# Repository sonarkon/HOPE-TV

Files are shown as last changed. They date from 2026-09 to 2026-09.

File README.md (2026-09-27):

# HopeTV

A tiny WiFi-connected "TV" built from a Wemos D1 mini (ESP8266) and a 1.44"
128x128 SPI TFT display (ST7735). Shows a color test pattern, classic
black/white TV static, a bouncing-ball animation, a playlist of looping
Motion-JPEG clips and still images, or a dedicated photo slideshow — all
remote-controllable over OSC (or a Serial console, for testing without an
OSC sender).

## Hardware

- Wemos D1 mini (ESP8266 / ESP-12)
- 1.44" SPI TFT, 128x128, ST7735 driver (commonly sold as "1.44 TFT LCD
  Display Module ST7735 128x128")
- USB power (5V) or a regulated 3.0–3.6V source wired directly to the 3V3 pin

## Pinout

One firmware, two supported wiring layouts — which one is active is chosen
at runtime via the `pinout` key in `config.txt` (`v2` or `prototyp`, see
below), no code changes needed. `v2` is the current/default board with a
re-laid-out, shorter-wire layout; `prototyp` is the original wiring.

| Display pin | `v2` (default) | `prototyp` (original) | Note |
|---|---|---|---|
| VCC | 3V3 | 3V3 | |
| GND | GND | GND | |
| CS | D4 (GPIO2) | D2 (GPIO4) | deliberately never D8 (boot issues) |
| RESET | D3 (GPIO0) | D4 (GPIO2) | |
| A0 / DC | D2 (GPIO4) | D3 (GPIO0) | |
| SDA / MOSI | D7 (GPIO13) | D7 (GPIO13) | Hardware SPI MOSI, fixed on the ESP8266 |
| SCK | D5 (GPIO14) | D5 (GPIO14) | Hardware SPI SCK, fixed on the ESP8266 |
| LED / Backlight | D1 (GPIO5) | D1 (GPIO5) | PWM-controlled, see Brightness/Power note below |

D0 and D8 are deliberately avoided in both layouts: they have special
boot-strapping functions and can easily cause boot loops or a dead display.

### Brightness/Power

The backlight LED is wired to **D1 (GPIO5)**, not straight to 3V3, so
`/hopetv/brightness` and `/hopetv/power` can dim/switch it via PWM. Per the
module's datasheet, the LED pin is a 3.3V logic control input ("high level
lighting"), not a raw LED — driving it directly from a GPIO without a
transistor is fine.

## Setup

1. **Board package**: add `http://arduino.esp8266.com/stable/package_esp8266com_index.json`
   under Additional Board Manager URLs, then install the ESP8266 package and
   select board **"LOLIN(WEMOS) D1 R2 & mini"**.
2. **Flash size**: Tools → Flash Size → a scheme with at least ~2MB of
   filesystem space (e.g. "4MB (FS:3MB OTA:~512KB)").
3. **Libraries** (via Library Manager):
   - `Adafruit GFX Library`
   - `Adafruit ST7735 and ST7789 Library` (a version with `enableDisplay()`)
   - `OSC` (by CNMAT / Adrian Freed)
   - `JPEGDEC` (by bitbank2)
4. **WiFi/OSC config**: copy `hopetv/data/config.example.txt` to
   `hopetv/data/config.txt` and fill in your own `ssid`/`password` (and
   `pinout`, if you're on the `prototyp` wiring). `config.txt` is gitignored
   on purpose — never commit your real WiFi credentials.
5. **Upload the data folder** with a LittleFS uploader (IDE 2.x: the
   [arduino-littlefs-upload](https://github.com/earlephilhower/arduino-littlefs-upload)
   plugin, run via the command palette — "Upload LittleFS to Pico/ESP8266/ESP32";
   IDE 1.8.x: the "ESP8266 LittleFS Data Upload" menu item). This uploads
   `config.txt`, the clip files, and `slideshow/`.
6. **Flash the sketch** normally.

If `config.txt` is missing, the sketch falls back to the placeholder
defaults hardcoded in the `.ino` file (`YOUR_WIFI_SSID` / `YOUR_WIFI_PASSWORD`),
which will simply fail to connect — always use a real `config.txt` for
actual WiFi use.

WiFi connects in the background: `WiFi.begin()` fires immediately at boot
(non-blocking), while the boot screen draws the clip list etc.; by the time
it actually waits for a result, part or all of the connect time has usually
already passed. Listing found clip names on the boot screen is capped at a
total of 5 seconds regardless of how many there are (a fixed 1s/clip
delay doesn't scale once you have a dozen+ clips).

## Clip playback (Motion-JPEG / stills)

Drop any number of 128x128 clip files into `data/` and upload them with the
filesystem tool — they're auto-detected at boot (sorted alphabetically,
addressable by index 0, 1, 2, ... — see the Serial `clips` command), and
each plays with the decoder matching its extension:

| Extension | Decoder | Notes |
|---|---|---|
| `.mjpg` | custom Motion-JPEG player (see below), via `JPEGDEC` | the only animated clip format |
| `.jpg` / `.jpeg` | `JPEGDEC`, decoded once | a lone still image, just held on screen |

**No animated-GIF support** — it was dropped deliberately. `AnimatedGIF`'s
own global decode-state object alone used ~24KB; combined with `JPEGDEC`
(added for stills/slideshow, ~18KB heap-allocated) that left almost no RAM
headroom on the ESP8266's small 80KB region for global/static variables
(90% used, no room for anything else). Dropping `AnimatedGIF` and
re-encoding old `.gif` clips as `.mjpg` instead brought that down to 60% —
and the two example clips got *smaller* in the process (see below). Old
`.gif` files can be converted the same way as any other source video (just
point ffmpeg at the `.gif` as input instead of a video file).

By default the device boots straight into clip mode and loops `clip2.mjpg`
if present, otherwise the first file found; no cycling through the other
modes unless you turn that on explicitly (`/hopetv/auto 1`) — and no
auto-advancing through the whole clip playlist either, `/hopetv/clip
<index>` (or the Serial `clip` command) just jumps to and loops/holds one
specific clip.

**`.mjpg` is not a standard container** — it's a tiny custom format made for
this project (see `tools/frame_mjpeg.py`): repeated `[4-byte little-endian
frame length][that many JPEG bytes]`, nothing else. That makes on-device
frame reading trivial (a length-prefixed read, no marker-scanning), at the
cost of not being playable by anything other than this firmware.

**Creating a new `.mjpg` clip**, roughly (adjust the crop values to your
source video/GIF — check for letterboxing/aspect ratio first):

```bash
ffmpeg -i input.mov -vf "crop=<w>:<h>:<x>:<y>,scale=128:128:flags=lanczos,fps=12" \
  -c:v mjpeg -huffman default -pix_fmt yuvj420p -q:v 10 -an -f mjpeg raw.mjpeg
python3 tools/frame_mjpeg.py raw.mjpeg clipN.mjpg
```

**`-huffman default -pix_fmt yuvj420p` are required, not optional.** FFmpeg's
mjpeg encoder defaults to per-frame-optimized ("optimal") Huffman tables and
a non-canonical chroma subsampling layout; both are valid JPEG but JPEGDEC
(the decoder this firmware uses) fails to decode the vast majority of frames
encoded that way — the exact symptom is clips/stills that look glitchy
(color noise, torn/shifted rows, wrong colors) on the device, verified by
running every frame of an affected clip through JPEGDEC's own reference
decoder offline. `-huffman default` forces the standard JPEG Huffman tables
and `-pix_fmt yuvj420p` forces canonical 4:2:0 subsampling — together these
reliably produce frames JPEGDEC decodes correctly.

Keep clips short (a few seconds) — file size scales with length; `q:v 10`
at 12fps runs well under 100KB for a several-second clip. LittleFS space is
limited to a few MB total.

## Slideshow

A separate, dedicated mode for cycling through photos, independent of the
clip playlist above: drop `.jpg`/`.jpeg` stills into `data/slideshow/` and
upload them — `/hopetv/slideshow 1` (or Serial `slideshow 1`) switches to
it, each image is shown before auto-advancing to the next, looping forever.
`/hopetv/slideshow 0` returns to clip mode. Default is 4 seconds/image,
adjustable with `/hopetv/slideshow/speed <seconds>` (or Serial `slidespeed
<seconds>`), e.g. `slidespeed 2.5`.

Optionally, each transition can fade to black, swap the image, then fade
back in via backlight PWM dimming, same mechanism as `/hopetv/brightness`.
Off by default; enable/adjust it with `/hopetv/slideshow/fade <ms>` (or
Serial `slidefade <ms>`), where `<ms>` is the total fade duration (0 turns
it off again), e.g. `slidefade 1000` for a 1-second fade. This isn't a true
pixel crossfade between the two images (that would need two full 128x128
framebuffers in RAM at once, ~64KB, more than reliably fits alongside WiFi +
JPEGDEC), but reads as a clean fade transition in practice.

```bash
ffmpeg -i input.jpg -vf "crop=min(iw\,ih):min(iw\,ih):(iw-min(iw\,ih))/2:(ih-min(iw\,ih))/2,\
scale=128:128:flags=lanczos" -huffman default -pix_fmt yuvj420p -update 1 -q:v 5 output.jpg
```

Same `-huffman default -pix_fmt yuvj420p` requirement as clips above (see
note there) — without it, stills decode just as unreliably as clips do.

## OSC commands (default port 9000)

| Address | Type | Meaning |
|---|---|---|
| `/hopetv/mode` | int (0-3) | 0=test pattern, 1=noise, 2=animation, 3=clip; disables auto-cycling |
| `/hopetv/auto` | int (0/1) | auto mode-cycling off/on |
| `/hopetv/debug` | int (0-2) | 0=off, 1=info screen (IP/port/clip+slide count/last command), 2=file list of found clips (paginated every 2s if needed) |
| `/hopetv/power` | int (0/1) | display off/on |
| `/hopetv/brightness` | float (0.0-1.0) | backlight brightness |
| `/hopetv/fps` | float (1-60) | frame rate for noise/animation (MJPEG clips run at their own native pace) |
| `/hopetv/bw` | int (0/1) | black & white filter, applied to test pattern, animation, and all clip/slideshow playback |
| `/hopetv/clip` | int (index) | select a clip by index (0-based, alphabetical — see Serial `clips`), switches to clip mode |
| `/hopetv/clip/id` | int (number) | select a clip by its filename number prefix (e.g. `3` → `03_mond_1.jpg`), independent of list position; Serial `clipid 3` |
| `/hopetv/slideshow` | int (0/1) | slideshow mode off/on (see Slideshow section above) |
| `/hopetv/slideshow/speed` | float (seconds) | seconds per slideshow image (default 4) |
| `/hopetv/slideshow/fade` | int (ms) | total fade transition duration; 0 = off (default) |

The address must match exactly (lowercase, one leading slash, no spaces) or
the message is received but ignored. Every received OSC message is echoed
over Serial (`OSC empfangen: <address> <value>`) followed by whether it
matched a known command — and in debug mode 1, the on-screen "Letzter OSC:"
line shows `[OK]` or `[?]` right next to the last command, so a typo in the
sender is easy to spot without a Serial Monitor open.

## Testing without an OSC sender

The exact same set of commands also works by typing into the Serial Monitor
(115200 baud, line ending set to "Newline") — just drop the `/hopetv/`
prefix: `mode 3`, `brightness 0.5`, `clip 1`, `slideshow 1`, `slidespeed
2.5`, `slidefade 1000`, `clips` (lists found clips + slide count), `help`
(full command list).

## Repo layout

```
hopetv/             the sketch: hopetv.ino, data/ (clips, slideshow/, config),
                     videoclips/ (raw source clips/photos, gitignored),
                     3d print/ (enclosure STL files)
tools/               frame_mjpeg.py - converts a raw ffmpeg MJPEG stream into
                     the custom length-prefixed .mjpg format this firmware reads
```

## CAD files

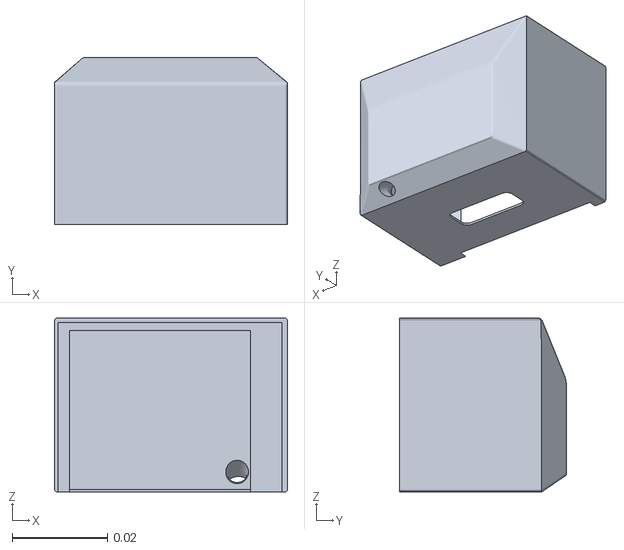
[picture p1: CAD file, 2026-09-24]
hopetv/3d print/back_3.stl
0.049 x 0.0351 x 0.0366

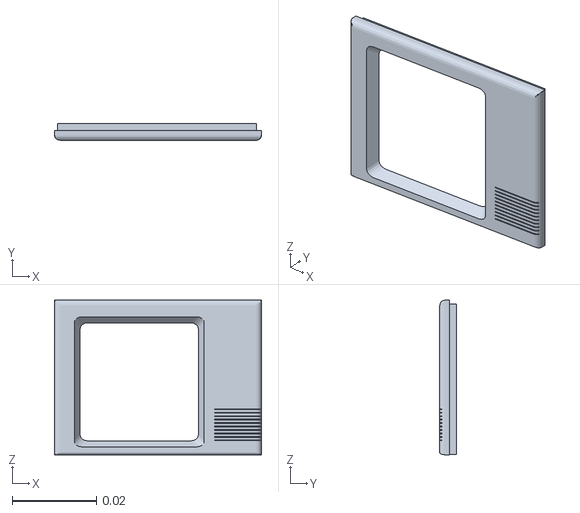
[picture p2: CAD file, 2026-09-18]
hopetv/3d print/front_3.stl
0.0491 x 0.00393 x 0.0367

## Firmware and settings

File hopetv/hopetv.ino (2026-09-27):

// D1 mini (ESP8266/ESP-12) + 1.44" SPI TFT 128x128 (ST7735, "v1.1" China clone module)
//
// Wiring (Hardware SPI):
//   LED/Backlight -> D1 (GPIO5) - PWM-controlled, see Brightness/Power note below
//   SCK           -> D5 (GPIO14)
//   SDA/MOSI      -> D7 (GPIO13)
//   A0/DC         -> D3 (GPIO0)
//   RESET         -> D4 (GPIO2)
//   CS            -> D2 (GPIO4)
//   VCC           -> 3V3
//   GND           -> GND
//
// Brightness/Power:
//   The backlight LED is wired to D1 (GPIO5), not straight to 3V3, so
//   /hopetv/brightness and /hopetv/power can dim/switch it via PWM. Per the
//   manufacturer datasheet, the LED pin is a logic control input (3.3V TTL,
//   "high level lighting"), not a raw LED pin - driving it directly from a
//   GPIO without a transistor is fine.
//
// Libraries (install via the Library Manager):
//   "Adafruit GFX Library"
//   "Adafruit ST7735 and ST7789 Library" (version with enableDisplay()!)
//   "OSC" (by CNMAT / Adrian Freed)
//   "JPEGDEC" (by bitbank2)
// LittleFS, ESP8266WiFi, WiFiUdp are part of the ESP8266 board package.
//
// Clip files: drop any number of .mjpg / .jpg(.jpeg) files (128x128) into
// the /data folder and upload them with the "ESP8266 LittleFS Data Upload"
// plugin - they are auto-detected at boot (sorted alphabetically,
// addressable via index 0,1,2,..., see the serial command "clips"), and each
// plays with the decoder matching its extension: .mjpg via a small custom
// Motion-JPEG player (see below), a lone .jpg/.jpeg is treated as a still
// image and just held on screen. (No animated-GIF support: it was dropped
// deliberately - the AnimatedGIF library's own global decode-state object
// alone used ~24KB, which combined with JPEGDEC left no RAM headroom on the
// ESP8266's small 80KB region for global/static variables. Re-encode old
// .gif clips to .mjpg with tools/frame_mjpeg.py instead - typically smaller
// files too.) Default behavior: the device boots straight into clip mode
// and loops clip2.mjpg if present, otherwise the first file found (no
// auto-cycling through all modes).
//
// .mjpg format: NOT a standard container - a simple custom format made for
// this project (see ../tools/frame_mjpeg.py in the repo root): repeated
// [4-byte little-endian frame length][one JFIF/JPEG frame's bytes], nothing
// else. Makes on-device frame reading trivial (no marker-scanning needed).
// To make one: encode a short 128x128 clip as concatenated JPEG frames with
// ffmpeg, e.g.
//   ffmpeg -i input.mov -vf fps=12 -c:v mjpeg -q:v 10 -an -f mjpeg raw.mjpeg
// then run `python3 tools/frame_mjpeg.py raw.mjpeg output.mjpg`.
//
// Slideshow: separate, dedicated mode - put .jpg/.jpeg stills into
// /data/slideshow/ and upload them; they auto-advance every N seconds
// (default 4, see /hopetv/slideshow/speed), looping forever, independent
// of the main clip playlist above.
//
// Optional: /data/config.txt for SSID/password/OSC port without reflashing.
//
// OSC commands (port from config.txt / default 9000):
//   /hopetv/mode           int   0=Test pattern 1=Noise 2=Animation 3=Clip
//   /hopetv/auto           int   0/1  auto mode-cycling off/on
//   /hopetv/debug          int   0=off 1=info (IP/port/clip+slide count/last command)
//                                 2=file list (found clips, paginated every 2s)
//   /hopetv/power          int   0/1  display off/on
//   /hopetv/brightness     float 0.0-1.0  backlight brightness (see note above)
//   /hopetv/fps            float 1-60  frame rate for noise/animation
//   /hopetv/bw             int   0/1  black & white filter off/on
//   /hopetv/clip           int   index  select a clip by index (0-based, alphabetically
//                                 sorted, see serial "clips"), switches to clip mode
//   /hopetv/clip/id        int   number  select a clip by its filename number prefix
//                                 (e.g. 3 -> "03_mond_1.jpg"), independent of list position (id, not index)
//   /hopetv/slideshow      int   0/1  slideshow mode off/on (see above)
//   /hopetv/slideshow/speed float seconds per slideshow image (default 4)
//   /hopetv/slideshow/fade int   ms   total fade transition duration; 0 = off (default)
//
// The same commands also work via the Serial Monitor (115200 baud, line
// ending "Newline"), no OSC sender needed for testing: e.g. "mode 3",
// "brightness 0.5", "clip 1", "slidespeed 2.5", "slidefade 1000".
// "help" shows the full list.
// IMPORTANT: serial commands need NO "/hopetv/" prefix (just "mode 3"), but
// real OSC messages DO (full "/hopetv/mode 3", exact, lowercase, one leading
// slash) - otherwise the message is received/displayed but no action is
// executed. In debug mode 1, "Last OSC:" shows [OK] (address recognized) or
// [?] (no matching address) right after the last command.

#include <Adafruit_GFX.h>
#include <Adafruit_ST7735.h>
#include <SPI.h>
#include <ESP8266WiFi.h>
#include <WiFiUdp.h>
#include <LittleFS.h>
#include <OSCMessage.h>
#include <JPEGDEC.h>

Adafruit_ST7735 *tft;
int8_t pinCS, pinDC, pinRST, pinBacklight;

struct Config {
  String ssid = "YOUR_WIFI_SSID";
  String password = "YOUR_WIFI_PASSWORD";
  uint16_t oscPort = 9000;
  String pinout = "v2"; // "v2" (default, new board) or "prototyp" (old pinout)
} config;

// Pinout "prototyp": CS=D2 DC=D3 RST=D4 LED=D1 (hardware SPI SCK=D5/MOSI=D7 always fixed)
// Pinout "v2":       CS=D4 DC=D2 RST=D3 LED=D1
void waehlePinout() {
  if (config.pinout == "prototyp") {
    pinCS = D2;
    pinDC = D3;
    pinRST = D4;
    pinBacklight = D1;
  } else {
    pinCS = D4;
    pinDC = D2;
    pinRST = D3;
    pinBacklight = D1;
  }
  Serial.print("Pinout: ");
  Serial.println(config.pinout);
}

WiFiUDP udp;

// Allocated on the heap in setup(), not a global object: JPEGDEC's internal
// decode buffers/Huffman tables are ~18KB, which alone would overflow the
// ESP8266's small (80KB) fixed region for global/static variables.
JPEGDEC *jpeg;

enum ClipTyp { CLIP_MJPG, CLIP_STILL };

#define MAX_CLIPS 48
String clipListe[MAX_CLIPS];
ClipTyp clipTypListe[MAX_CLIPS];
int anzahlClips = 0;
String aktuellerClipPfad = "/01_clip2.mjpg"; // may be overridden by sucheClips()/waehleStandardClip()
ClipTyp aktuellerClipTyp = CLIP_MJPG;

// Motion-JPEG playback (custom .mjpg container, see header comment above)
File mjpgFile;
bool mjpgOffen = false;
uint8_t mjpgFrameBuf[8192]; // generous headroom over the ~3.3KB max frame seen so far
const unsigned long MJPG_FRAME_MS = 83; // ~12 fps, matches how clips are encoded

// Slideshow: separate file list + own mode, independent of the clip playlist
#define MAX_SLIDES 32
String slideListe[MAX_SLIDES];
int anzahlSlides = 0;
int slideIndex = 0;
unsigned long slideStart = 0;
unsigned long slideDauerMs = 4000; // per image, adjustable via /hopetv/slideshow/speed
unsigned long slideFadeMs = 0; // total fade transition duration; 0 = off (default), see /hopetv/slideshow/fade

// Mode name kept as "GIFMODUS" for historical reasons (this used to be
// GIF-only) - it's now the general clip-playlist mode (MJPEG + stills).
enum Mode { TESTBILD, RAUSCHEN, ANIMATION, GIFMODUS, SLIDESHOW, DEBUG };
Mode mode = GIFMODUS; // default: loop the default clip directly, no auto-cycling
bool autoCycle = false;
bool powerOn = true;
bool bwFilter = false;
float brightness = 1.0f;
unsigned long modeStart = 0;
const unsigned long MODE_DAUER = 6000; // ms per mode

unsigned long frameIntervalMs = 33; // ~30 fps initial default
unsigned long lastFrame = 0;
unsigned long lastDebugDraw = 0;
int debugModus = 0; // 0=off, 1=info, 2=file list
Mode modusVorDebug = GIFMODUS; // saved on entering debug mode, restored on exit
bool autoCycleVorDebug = false;
int filelistSeite = 0;
int filelistSeitenAnzahl = 1;
const int FILELIST_ZEILEN_PRO_SEITE = 8;
int letzteHelligkeitProzent = -1;
int letzteFps = -1;
String letzterAngezeigterOsc = "";
String letzterOscBefehl = "-";

bool bootSplashActive = true;
unsigned long bootSplashStart = 0;
const unsigned long BOOT_SPLASH_DAUER = 3000; // IP/status display time after WiFi result, before clip playback starts
unsigned long wlanStartZeit = 0; // set by starteWLAN(), used to cap the total connect wait

// State for the ball animation
float ballX = 64, ballY = 64;
float ballVX = 2.3, ballVY = 1.7;
const int ballR = 6;

void setup() {
  Serial.begin(115200);

  ladeConfig(); // mounts LittleFS, reads SSID/password/port/pinout
  waehlePinout();
  sucheClips();
  sucheSlideshow();
  waehleStandardClip();

  tft = new Adafruit_ST7735(pinCS, pinDC, pinRST);
  tft->initR(INITR_144GREENTAB); // correct for 1.44" 128x128 v1.1
  tft->setRotation(1); // +90 degrees (was -90, rotated another 180)
  tft->fillScreen(ST77XX_BLACK);

  pinMode(pinBacklight, OUTPUT);
  analogWriteRange(1023);
  setzeHelligkeit(brightness);

  jpeg = new JPEGDEC();

  Serial.println("Standard-Clip: " + aktuellerClipPfad + " (Typ: " + String(aktuellerClipTyp == CLIP_MJPG ? "MJPG" : "STILL") + ")");

  // Fire off the WiFi connection now (non-blocking) so it happens in the
  // background while the boot sequence below draws the clip list etc. -
  // by the time we get to actually waiting for it, some/all of the connect
  // time has likely already elapsed.
  starteWLAN();

  bootSplashActive = true;
  bootSplashStart = millis();
  zeichneBootSequenz();
}

void loop() {
  pruefeOSC();
  pruefeSerialBefehle();

  if (bootSplashActive) {
    if (millis() - bootSplashStart > BOOT_SPLASH_DAUER) {
      bootSplashActive = false;
      tft->fillScreen(ST77XX_BLACK);
      if (mode == TESTBILD) zeichneTestbild();
      modeStart = millis();
    }
    return;
  }

  if (!powerOn) return;

  if (mode == SLIDESHOW) {
    if (millis() - slideStart > slideDauerMs) {
      zeigeSlide(slideIndex + 1);
    }
    return;
  }

  if (mode == DEBUG) {
    if (debugModus == 2) {
      // only redraw at all when there are multiple pages (to page through) -
      // if everything fits on one page it was already drawn on entry
      if (filelistSeitenAnzahl > 1 && millis() - lastDebugDraw > 2000) {
        zeichneDateiliste();
        lastDebugDraw = millis();
      }
    } else if (millis() - lastDebugDraw > 1000) {
      zeichneDebugDynamisch();
      lastDebugDraw = millis();
    }
    return;
  }

  if (autoCycle && millis() - modeStart > MODE_DAUER) {
    modeStart = millis();
    if (mode == GIFMODUS) beendeMjpeg();
    mode = (Mode)((mode + 1) % 4); // cycles TESTBILD/RAUSCHEN/ANIMATION/GIFMODUS
    tft->fillScreen(ST77XX_BLACK);
    if (mode == TESTBILD) zeichneTestbild();
    else if (mode == GIFMODUS && aktuellerClipTyp == CLIP_STILL) zeigeStandbild(aktuellerClipPfad);
  }

  if (mode == GIFMODUS) {
    if (aktuellerClipTyp == CLIP_MJPG) {
      if (millis() - lastFrame >= MJPG_FRAME_MS) {
        lastFrame = millis();
        spieleMjpegFrame();
      }
    }
    // CLIP_STILL: nothing to do each frame, already drawn once on selection
  } else if (millis() - lastFrame >= frameIntervalMs) {
    lastFrame = millis();
    switch (mode) {
      case TESTBILD:
        // already drawn, nothing to do
        break;
      case RAUSCHEN:
        zeichneRauschen();
        break;
      case ANIMATION:
        animiereBall();
        break;
      default:
        break;
    }
  }
}

void ladeConfig() {
  if (!LittleFS.begin()) {
    Serial.println("LittleFS-Mount fehlgeschlagen, nutze Standardwerte");
    return;
  }
  if (!LittleFS.exists("/config.txt")) {
    Serial.println("Keine config.txt gefunden, nutze Standardwerte");
    return;
  }
  File f = LittleFS.open("/config.txt", "r");
  while (f.available()) {
    String line = f.readStringUntil('\n');
    line.trim();
    if (line.length() == 0 || line.startsWith("#")) continue;
    int eq = line.indexOf('=');
    if (eq < 0) continue;
    String key = line.substring(0, eq);
    String val = line.substring(eq + 1);
    key.trim();
    val.trim();
    if (key == "ssid") config.ssid = val;
    else if (key == "password") config.password = val;
    else if (key == "oscport") config.oscPort = (uint16_t)val.toInt();
    else if (key == "pinout") config.pinout = val;
  }
  f.close();
  Serial.println("config.txt geladen");
}

// Recognizes .mjpg (custom container, see header) and .jpg/.jpeg (single
// still image) - anything else in the root folder is ignored, so e.g.
// config.txt or the slideshow/ subfolder are naturally skipped.
void sucheClips() {
  anzahlClips = 0;
  Dir dir = LittleFS.openDir("/");
  while (dir.next() && anzahlClips < MAX_CLIPS) {
    String name = dir.fileName();
    String nameLower = name;
    nameLower.toLowerCase();
    ClipTyp typ;
    if (nameLower.endsWith(".mjpg")) typ = CLIP_MJPG;
    else if (nameLower.endsWith(".jpg") || nameLower.endsWith(".jpeg")) typ = CLIP_STILL;
    else continue;
    if (!name.startsWith("/")) name = "/" + name;
    clipListe[anzahlClips] = name;
    clipTypListe[anzahlClips] = typ;
    anzahlClips++;
  }
  // simple sort (alphabetical, both arrays in lockstep), lists are small
  for (int i = 0; i < anzahlClips - 1; i++) {
    for (int j = 0; j < anzahlClips - 1 - i; j++) {
      if (clipListe[j] > clipListe[j + 1]) {
        String tauschName = clipListe[j];
        clipListe[j] = clipListe[j + 1];
        clipListe[j + 1] = tauschName;
        ClipTyp tauschTyp = clipTypListe[j];
        clipTypListe[j] = clipTypListe[j + 1];
        clipTypListe[j + 1] = tauschTyp;
      }
    }
  }
  filelistSeitenAnzahl = max(1, (anzahlClips + FILELIST_ZEILEN_PRO_SEITE - 1) / FILELIST_ZEILEN_PRO_SEITE);

  Serial.print(anzahlClips);
  Serial.println(" Clip-Datei(en) gefunden:");
  for (int i = 0; i < anzahlClips; i++) {
    Serial.print("  ");
    Serial.print(i);
    Serial.print(": ");
    Serial.println(clipListe[i]);
  }
}

// Scans /slideshow (separate from the main clip playlist above) for stills.
void sucheSlideshow() {
  anzahlSlides = 0;
  Dir dir = LittleFS.openDir("/slideshow");
  while (dir.next() && anzahlSlides < MAX_SLIDES) {
    String name = dir.fileName();
    int slash = name.lastIndexOf('/');
    if (slash >= 0) name = name.substring(slash + 1); // defensive: keep just the basename
    String nameLower = name;
    nameLower.toLowerCase();
    if (!(nameLower.endsWith(".jpg") || nameLower.endsWith(".jpeg"))) continue;
    slideListe[anzahlSlides++] = "/slideshow/" + name;
  }
  for (int i = 0; i < anzahlSlides - 1; i++) {
    for (int j = 0; j < anzahlSlides - 1 - i; j++) {
      if (slideListe[j] > slideListe[j + 1]) {
        String tausch = slideListe[j];
        slideListe[j] = slideListe[j + 1];
        slideListe[j + 1] = tausch;
      }
    }
  }
  Serial.print(anzahlSlides);
  Serial.println(" Slideshow-Bild(er) gefunden");
}

void waehleStandardClip() {
  for (int i = 0; i < anzahlClips; i++) {
    if (clipListe[i] == "/01_clip2.mjpg" || clipListe[i] == "/clip2.mjpg") {
      aktuellerClipPfad = clipListe[i];
      aktuellerClipTyp = clipTypListe[i];
      return;
    }
  }
  if (anzahlClips > 0) {
    aktuellerClipPfad = clipListe[0];
    aktuellerClipTyp = clipTypListe[0];
  }
}

// Starts the WiFi connection attempt and returns immediately - WiFi.begin()
// itself is non-blocking, the ESP8266 connects in the background. Call
// zeigeWLANStatus() later to wait for/show the result.
void starteWLAN() {
  wlanStartZeit = millis();
  WiFi.mode(WIFI_STA);
  WiFi.begin(config.ssid.c_str(), config.password.c_str());
  Serial.print("Verbinde mit ");
  Serial.println(config.ssid);
}

// Waits for (and shows) the outcome of the WiFi connection started earlier
// by starteWLAN(). The 15s timeout is measured from wlanStartZeit, not from
// here - if other boot steps already used up several seconds in the
// meantime, only the remaining time is waited (often zero: already connected).
void zeigeWLANStatus(int y) {
  const char* punkte[3] = {".  ", ".. ", "..."};
  int punktIndex = 0;
  const unsigned long GESAMT_TIMEOUT = 15000;

  while (WiFi.status() != WL_CONNECTED && millis() - wlanStartZeit < GESAMT_TIMEOUT) {
    delay(300);
    Serial.print(".");

    String status;
    switch (WiFi.status()) {
      case WL_NO_SSID_AVAIL:   status = "SSID fehlt"; break;
      case WL_CONNECT_FAILED:  status = "Fehlgeschlagen"; break;
      case WL_CONNECTION_LOST: status = "Verbindung weg"; break;
      default:                 status = "Verbinde"; break;
    }

    tft->fillRect(0, y, 128, 10, ST77XX_BLACK);
    tft->setCursor(4, y);
    tft->print(status + punkte[punktIndex % 3]);
    punktIndex++;
  }

  tft->fillRect(0, y, 128, 10, ST77XX_BLACK);
  tft->setCursor(4, y);
  if (WiFi.status() == WL_CONNECTED) {
    Serial.println();
    Serial.print("Verbunden, IP: ");
    Serial.println(WiFi.localIP());
    udp.begin(config.oscPort);
    Serial.print("OSC-Empfang auf Port ");
    Serial.println(config.oscPort);
    tft->print("WLAN verbunden");
  } else {
    Serial.println();
    Serial.println("WLAN-Verbindung fehlgeschlagen - laeuft offline weiter");
    tft->print("WLAN fehlgeschlagen");
    delay(2000); // leave it up longer, easy to read
  }
}

void setzeHelligkeit(float b) {
  b = constrain(b, 0.0f, 1.0f);
  analogWrite(pinBacklight, (int)(b * 1023));
}

// Core functions: shared by both OSC handlers AND serial test commands

void setzeModus(int m) {
  if (mode == GIFMODUS) beendeMjpeg();
  mode = (Mode)constrain(m, 0, 3);
  autoCycle = false;
  tft->fillScreen(ST77XX_BLACK);
  if (mode == TESTBILD) zeichneTestbild();
  else if (mode == GIFMODUS && aktuellerClipTyp == CLIP_STILL) zeigeStandbild(aktuellerClipPfad);
  modeStart = millis();
}

void setzeAuto(bool an) {
  autoCycle = an;
  modeStart = millis();
}

void setzeDebugModus(int stufe) {
  int neueStufe = constrain(stufe, 0, 2);

  if (neueStufe > 0 && debugModus == 0) {
    // first entry into debug mode: remember the current state so it can be
    // restored on exit (debug 0) instead of always jumping back to the test pattern
    modusVorDebug = mode;
    autoCycleVorDebug = autoCycle;
  }
  debugModus = neueStufe;

  if (debugModus > 0) {
    if (mode == GIFMODUS) beendeMjpeg();
    mode = DEBUG;
    autoCycle = false;
    filelistSeite = 0;
    if (debugModus == 2) {
      zeichneDateiliste(); // show the first page immediately
    } else {
      zeichneDebugStatisch("Debug"); // title/SSID/IP/port drawn once, no flicker afterwards
      letzteHelligkeitProzent = -1; // forces an immediate draw on the first call
      letzteFps = -1;
      letzterAngezeigterOsc = "";
      zeichneDebugDynamisch();
    }
    lastDebugDraw = millis();
  } else {
    mode = modusVorDebug;
    autoCycle = autoCycleVorDebug;
    tft->fillScreen(ST77XX_BLACK);
    if (mode == TESTBILD) zeichneTestbild();
    else if (mode == GIFMODUS && aktuellerClipTyp == CLIP_STILL) zeigeStandbild(aktuellerClipPfad);
    modeStart = millis();
  }
}

void setzePower(bool an) {
  powerOn = an;
  if (powerOn) {
    tft->enableDisplay(true);
    setzeHelligkeit(brightness);
  } else {
    setzeHelligkeit(0);
    tft->enableDisplay(false);
  }
}

void setzeBrightness(float b) {
  brightness = constrain(b, 0.0f, 1.0f);
  if (powerOn) setzeHelligkeit(brightness);
}

void setzeFps(float fps) {
  fps = constrain(fps, 1.0f, 60.0f);
  frameIntervalMs = (unsigned long)(1000.0f / fps);
}

void setzeBW(bool an) {
  bwFilter = an;
}

void setzeClip(int index) {
  if (anzahlClips == 0) {
    Serial.println("Keine Clip-Dateien gefunden (LittleFS-Upload gemacht?)");
    return;
  }
  index = constrain(index, 0, anzahlClips - 1);
  aktuellerClipPfad = clipListe[index];
  aktuellerClipTyp = clipTypListe[index];
  beendeMjpeg(); // closes whichever was open - the next frame opens the new clip
  mode = GIFMODUS;
  autoCycle = false;
  modeStart = millis();
  if (aktuellerClipTyp == CLIP_STILL) zeigeStandbild(aktuellerClipPfad);
}

// Selects the clip whose filename starts with the given number ("/03_x.jpg" -> 3).
void setzeClipId(int id) {
  for (int i = 0; i < anzahlClips; i++) {
    const char *p = clipListe[i].c_str() + 1; // skip leading '/'
    if (*p < '0' || *p > '9') continue;
    if (atoi(p) == id) {
      setzeClip(i);
      return;
    }
  }
  Serial.println("Kein Clip mit Praefix-ID " + String(id) + " gefunden");
}

void setzeSlideshow(bool an) {
  if (an) {
    if (anzahlSlides == 0) {
      Serial.println("Keine Slideshow-Bilder gefunden (data/slideshow/ hochgeladen?)");
      return;
    }
    if (mode == GIFMODUS) beendeMjpeg();
    mode = SLIDESHOW;
    autoCycle = false;
    zeigeSlide(0);
  } else {
    mode = GIFMODUS;
    autoCycle = false;
    tft->fillScreen(ST77XX_BLACK);
    if (aktuellerClipTyp == CLIP_STILL) zeigeStandbild(aktuellerClipPfad);
    modeStart = millis();
  }
}

void setzeSlideSpeed(float sekunden) {
  sekunden = constrain(sekunden, 0.5f, 600.0f);
  slideDauerMs = (unsigned long)(sekunden * 1000.0f);
}

void setzeSlideFade(int ms) {
  slideFadeMs = (unsigned long)constrain(ms, 0, 10000); // 0 = off
}

// OSC handlers: thin wrappers around the core functions above

void handleOscMode(OSCMessage &msg) {
  bootSplashActive = false;
  setzeModus(msg.getInt(0));
}

void handleOscAuto(OSCMessage &msg) {
  bootSplashActive = false;
  setzeAuto(msg.getInt(0) != 0);
}

void handleOscDebug(OSCMessage &msg) {
  bootSplashActive = false;
  setzeDebugModus(msg.getInt(0));
}

void handleOscPower(OSCMessage &msg) {
  bootSplashActive = false;
  setzePower(msg.getInt(0) != 0);
}

void handleOscBrightness(OSCMessage &msg) {
  bootSplashActive = false;
  setzeBrightness(msg.getFloat(0));
}

void handleOscFps(OSCMessage &msg) {
  bootSplashActive = false;
  setzeFps(msg.getFloat(0));
}

void handleOscBW(OSCMessage &msg) {
  bootSplashActive = false;
  setzeBW(msg.getInt(0) != 0);
}

void handleOscClip(OSCMessage &msg) {
  bootSplashActive = false;
  setzeClip(msg.getInt(0));
}

void handleOscClipId(OSCMessage &msg) {
  bootSplashActive = false;
  setzeClipId(msg.getInt(0));
}
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

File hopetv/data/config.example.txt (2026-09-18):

# Copy this file to config.txt and fill in your own values, then upload
# it with the LittleFS data upload tool (see README). If config.txt is
# missing, the sketch falls back to the placeholder defaults hardcoded in
# the .ino file, which will NOT connect to any real network.
ssid=YOUR_WIFI_SSID
password=YOUR_WIFI_PASSWORD
oscport=9000
# pinout=v2 (current/short-wire board, default) or pinout=prototyp (original board)
pinout=v2

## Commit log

2026-09-18 Initial commit: HopeTV OSC-controlled TFT display firmware
    D1 mini + ST7735 128x128 display showing a test pattern, TV static,
    a ball animation, or looping GIF clips, controllable over OSC or Serial.
    Two pinout profiles (prototype/v2) sharing one codebase, config-driven
    WiFi/pinout selection, and a standalone hardware bring-up diagnostic sketch.
    [back_1.stl, back_2.stl, back_3.stl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]
2026-09-18 Consolidate to a single sketch folder
    hopetv.ino was already identical between hopetv/ and hopetv_v2/ (pinout
    is selected at runtime via config.txt), so the duplicate hopetv_v2/ folder
    added nothing but confusion. Move its unique assets (video/, 3d print/)
    into hopetv/ and remove the duplicate. README's two pinout tables are now
    one merged table with a v2/prototyp column each.
    [back_1.stl, back_2.stl, back_3.stl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]
2026-09-18 Reorder pinout table to match the display's datasheet pin order
    Rows now follow the display module's own connector/datasheet order
    (VCC, GND, CS, RESET, A0, SDA, SCK, LED) instead of an arbitrary order,
    making it easier to cross-reference against the datasheet while wiring.
2026-09-24 Update enclosure STL files
    Remove superseded back_1/back_2/front_1/front_2 iterations, keep the
    current back_3/front_3 revision (back_3 updated).
    [back_1.stl, back_2.stl, back_3.stl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]
2026-09-24 Add Motion-JPEG clip playback and a dedicated photo slideshow mode
    Clip playlist now supports three file types by extension, auto-detected
    alongside the existing GIFs:
    - .gif -> AnimatedGIF (unchanged)
    - .mjpg -> a small custom Motion-JPEG player (JPEGDEC), using our own
    length-prefixed frame container (see tools/frame_mjpeg.py) since raw
    concatenated JPEG streams have no built-in frame index
    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
2026-09-25 Drop AnimatedGIF, cap boot clip listing, connect WiFi in the background, add slideshow speed control
    - Remove GIF support entirely (AnimatedGIF's global decode-state object
    alone used ~24KB; combined with JPEGDEC that left global/static RAM at
    90% used with no headroom - now 60%). Convert the two example clips
    (01_clip2, 02_clip1) from .gif to .mjpg - both end up smaller too
    (1.27MB->479KB and 401KB->112KB).
    - Boot sequence: listing found clip names is now capped at a total of 5s
    regardless of clip count, instead of a flat 1s/clip that didn't scale
    once there were a dozen+ clips.
    - WiFi now connects in the background: WiFi.begin() fires at the very
    start of setup() (non-blockin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
    [hopetv.ino]
2026-09-25 Add fade transition between slideshow images
    Each slide change fades to black, swaps the image, then fades back in
    (1s total) via backlight PWM dimming (needs the backlight rewiring
    already required for /hopetv/brightness). A true pixel crossfade would
    need two full 128x128 framebuffers in RAM simultaneously (~64KB), more
    than reliably fits alongside WiFi + JPEGDEC - the brightness-based fade
    needs no extra RAM and reads as a clean transition in practice.
    [hopetv.ino]
2026-09-25 Make slideshow fade off by default, add /hopetv/slideshow/fade, describe backlight wiring as standard
    The backlight wiring to D1 is now the fixed/standard layout, not an
    optional modification, so docs and comments describe it factually
    instead of as a "rewiring" step. Slideshow fade transition defaults
    to off and is now configurable in milliseconds via
    /hopetv/slideshow/fade (OSC) or slidefade (Serial), replacing the
    previous hardcoded always-on 1s fade.
    [hopetv.ino]
2026-09-25 Fix glitchy clip/slideshow playback and slow boot-to-clip time
    Root cause of the glitches: ffmpeg's mjpeg encoder defaults to
    per-frame-optimized Huffman tables and a non-canonical chroma
    subsampling layout. Both are valid JPEG, but JPEGDEC (the decoder
    this firmware uses) fails to decode the large majority of frames
    encoded that way, which showed up on-device as color noise,
    torn/shifted rows and wrong colors on nearly every clip and
    slideshow image. Verified by running every frame of the shipped
    assets through JPEGDEC's own reference decoder offline: 598/602
    frames failed before the fix, 0/623 after.
    - Re-encode all shipped clips, clip stills, and slideshow images
    with standard Huffman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
    [hopetv.ino]
2026-09-25 Shrink data assets - previous fix's higher quality overflowed LittleFS
    The Huffman/subsampling fix in the last commit re-encoded everything
    at Pillow quality=88, which fixed decoding but nearly doubled total
    size (1.0MB -> 2.0MB) and overflowed the device's LittleFS partition
    ("File system is full") during upload. Re-encoded again at quality=15
    (897KB total, 0/623 frames fail the same offline JPEGDEC check) to
    get back under the ~1.0MB that was known to fit, with headroom.
